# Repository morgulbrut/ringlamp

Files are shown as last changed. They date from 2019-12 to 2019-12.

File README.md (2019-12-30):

# ringlamp

Neopixel ringlamp, programmed in CircuitPython

## Repo

### housing

OpenSCAD file to generate the housing

### hardware

Hardware related stuff

### software

CircuitPython software.

#### code.py

Main: reads in 3 pots, and one switch.

The switch switches trough 6 modes, where the pots have slightly different functions:

 * **Mode 1:** warmwhite 
    * pot 1 sets the brightness
 * **Mode 2:** coldwhite 
    * pot 1 sets the brightness
 * **Mode 3:** RGB
    * pot 1 sets red
    * pot 2 sets green
    * pot 3 sets blue
 * **Mode 4:** split colors, half of the circle gets one color, the other half a second
    * pot 1 sets the brightness
    * pot 2 sets the rotation angle
    * pot 3 sets 10 different presets
 *  **Mode 5:** colorwheel
    * pot 1 sets the brightness
    * pot 2 rotates through the colorwheel
 * **Mode 6:** blend colors, every other LED gets color 1 or color 2 
    * pot 1 sets the brightness
    * pot 2 rotates through the colorwheel for color 1
    * pot 2 rotates through the colorwheel for color 2

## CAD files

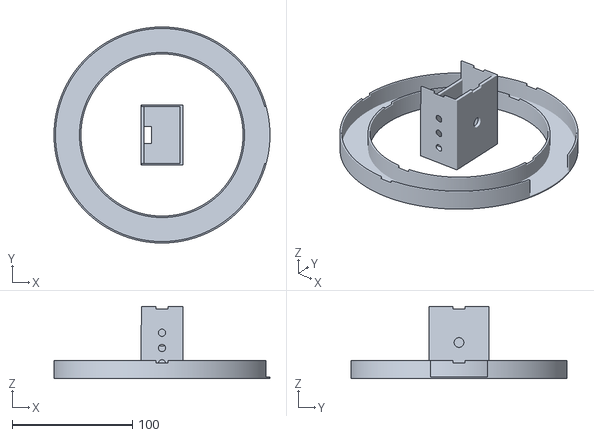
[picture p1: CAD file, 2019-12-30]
housing/ringlamp.stl
179.4 x 179.4 x 60.0

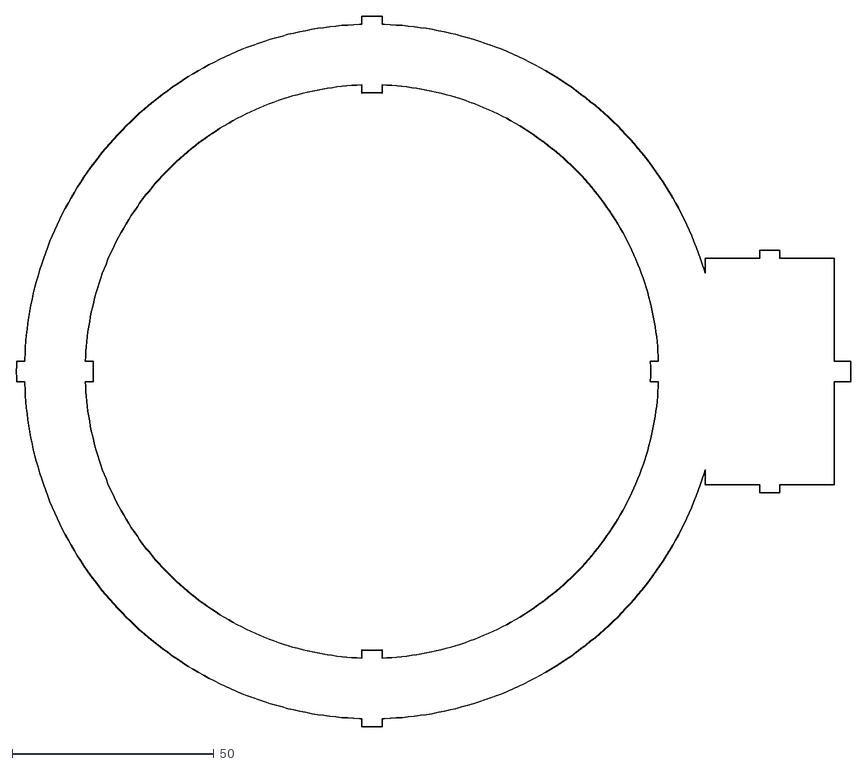
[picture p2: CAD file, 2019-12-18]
housing/cover.dxf
206.5 x 176.0

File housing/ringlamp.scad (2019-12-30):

LedRingDiameter = 157;   // [20:200]
LedRingWidth = 20;       // [5:20]
LedRingHeight = 15;      // [10:20]
WallThickness = 1.2;       // [1.0, 1.2, 2.0, 2.4, 4.0]
CompartementWidth = 50;  // [20:80]
CompartementHeight = 35; // [20:80]
CompartementLength = 60; // [20:120]
PotDistance = 12.7;        // [10.0, 12.7, 60.0]
PotCount = 3;            // [2:4]
PotShaft = 6;            // [4:10]
PlexiThickness = 2.0;    // [1.5, 2.0, 2.5, 3, 3.5, 4.0]
PlexiWidth = 10;         // [3:10]
ShowPart = 2;            // [0:Cover, 1:Cover2D, 2:Body, 3:BodyMounted, 4:All, 5:AllMounted]

inner1 = LedRingDiameter/2-WallThickness-LedRingWidth/2;
outer1 = LedRingDiameter/2+WallThickness+LedRingWidth/2;
inner2 = LedRingDiameter/2-LedRingWidth/2;
outer2 = LedRingDiameter/2+LedRingWidth/2;

compDist = sqrt(outer1*outer1-(CompartementWidth/2)*(CompartementWidth/2));

/* makes a ring
 o is the outer diameter
 i is the inner diameter
 h is the height
*/
module ring(o,i,h){
    difference(){
        cylinder($fn=360,h = h, r = o, center = false);
        translate([0,0,-.5]){
            cylinder($fn=360,h = h+1, r = i, center = false);
        }
    }
}


/* makes a cross out f two cubes, o x PlexiWidth x PlexiThickness
  for a plexi connections
  l is the size 
*/
module plexiCons(l){
    translate([0,0,(PlexiThickness+1)/2]){
        union(){
            cube([l+PlexiWidth,PlexiWidth,PlexiThickness+1],true);
            cube([PlexiWidth,l+PlexiWidth,PlexiThickness+1],true);
        }
    }
}


/* makes a bunch of holes for pots */
module potentiometers(){
    rotate([90,0,0]){
        for (a = [0 : PotCount - 1]) {
            translate([0,a*PotDistance,0]){
                cylinder($fn=360,h = CompartementWidth, r = PotShaft/2 , center = false);
            }
        }
    } 
}


/* makes the cover to lasercut */
module cover(){
    color("white"){
        difference(){
            union(){
                ring(outer1-0.1,inner1+0.1,PlexiThickness-0.1);
                translate([compDist+CompartementHeight/2-WallThickness,0,PlexiThickness/2]){
                    cube([CompartementHeight+WallThickness,CompartementWidth-0.1,PlexiThickness-0.1],true);
                }
            }
            translate([0,0,PlexiThickness]){
                body();
            }
        }
    }
}


/* makes the compartement for the controller to 3d print */
module controllerCompartement(){
    color("red"){
        translate([0,0,CompartementLength/2]){
            difference(){
                // outer cube
                cube([CompartementHeight,CompartementWidth,CompartementLength],true);
                translate([0,0,WallThickness]){
                    // make a shelF
                    cube([CompartementHeight-4*WallThickness,CompartementWidth-2*WallThickness,CompartementLength],true);   
                }
                translate([-(CompartementHeight/2),0,CompartementLength/2-LedRingHeight/2]){
        
                        cube([WallThickness,CompartementWidth+1,LedRingHeight+1],true); 
                        cube([CompartementHeight,CompartementWidth-2*WallThickness,LedRingHeight+1],true);
                }
                // holes for pots
                translate([0,0,-CompartementLength/2+PotDistance]){
                    potentiometers();
                }
                // notches for the plexi 
                translate([0,0,CompartementLength/2-PlexiThickness]){
                    plexiCons(90);
                }
                // mounting hole
                rotate([0,90,0]){
                    cylinder($fn=360,h = CompartementWidth, r = 4 , center = false);
                }
                // switch mounting hole
                rotate([-90,0,0]){
                    cylinder($fn=360,h = CompartementWidth, r = 3.1 , center = false);
                }
                // USB port
                translate([-CompartementHeight/2+4*WallThickness,0,-CompartementLength/2]){
                    cube([8,14,10],true);
                }
            }  
        }
    }
}


/* makes the ring for the LEDs to 3d print*/
module ledRing(){
    color("blue"){
        cutout = CompartementWidth-2*WallThickness;
        difference(){
            ring(outer1,inner1,LedRingHeight); 
            translate([0,0,WallThickness]){
                ring(outer2,inner2,LedRingHeight); 
            }
            translate([outer2-10,-cutout/2,WallThickness]){
                cube([20,cutout,LedRingHeight],false);   
            }
            translate([0,0,LedRingHeight-PlexiThickness]){
                plexiCons(outer1*2);
            }
        }
    }
}

/* connects a ring and a controller compartement to visualise the printed parts mounted */
module body(){
    translate([compDist+CompartementHeight/2,0,-(CompartementLength)]){
        controllerCompartement() ;
    }
    translate([0,0,-LedRingHeight]){
        ledRing();
    }
}



module ledRingCPL(){
    body();
    translate([0,0,-PlexiThickness]){
        cover();
    } 
}

if (ShowPart==0) cover();

if (ShowPart==1){
    render(){
        projection(){
            cover();
        }
    }
}

if (ShowPart==2){
    if (inner1 > CompartementWidth && inner1 > CompartementHeight ){
        controllerCompartement();
        ledRing();
    } else {
        controllerCompartement();
        translate([outer1+CompartementHeight,0,0]){
            ledRing();
        }
    }
}

if (ShowPart==3) body();

if (ShowPart==4){
    controllerCompartement();
    ledRing();
    translate([-LedRingDiameter-100,0,0]){
        cover();
    }
}

if (ShowPart==5) ledRingCPL();

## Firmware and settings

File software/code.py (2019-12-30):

from ring import Ring, Colors
import time
import digitalio
import board
import analogio


def ready():
    r.set_brightness(0.1)
    r.fill(Colors.GREEN)
    time.sleep(.5)
    r.fill(Colors.hex2rgb('#ffaa00'))
    time.sleep(.5)
    r.split_colors(Colors.BLUE,Colors.RED)
    time.sleep(1)
    r.blend_colors(Colors.COLDWHITE,Colors.YELLOW)
    time.sleep(1)
    r.fill(Colors.BLACK)


def get_value(pin):
    return (pin.value) / 65536.0



def get_byte_value(pin):
    return int((pin.value * 255) / 65536)


def main():
    mode = 3 # see README.md
    
    mode_sw = digitalio.DigitalInOut(board.D4)
    mode_sw.direction = digitalio.Direction.INPUT
    mode_sw.pull = digitalio.Pull.UP

    pot1 = analogio.AnalogIn(board.D1)
    pot2 = analogio.AnalogIn(board.D2)
    pot3 = analogio.AnalogIn(board.D3)

    while True:
        if not mode_sw.value:
            mode = (mode + 1) % 6
            time.sleep(0.2)
        if mode == 0:
            r.fill(Colors.WARMWHITE)
            r.set_brightness(get_value(pot1)*.7)
        elif mode == 1:
            r.fill(Colors.COLDWHITE)
            r.set_brightness(get_value(pot1)*.7)
        elif mode == 2:
            rval = get_byte_value(pot1)
            gval = get_byte_value(pot2)
            bval = get_byte_value(pot3)
            r.fill((rval,gval,bval))
            r.set_brightness(.7)
        elif mode == 3:
            start = int(get_value(pot2)* 60)
            cols = int(get_value(pot3)* 11)
            if cols == 0:
                r.split_colors(Colors.WARMWHITE,Colors.BLACK, start)
            elif cols == 1:
                r.split_colors(Colors.COLDWHITE,Colors.BLACK, start)
            elif cols == 2:
                r.split_colors(Colors.GREEN,Colors.WARMWHITE, start)
            elif cols == 3:
                r.split_colors(Colors.RED,Colors.WARMWHITE, start)
            elif cols == 4:
                r.split_colors(Colors.BLUE,Colors.WARMWHITE, start)
            elif cols == 5:
                r.split_colors(Colors.RED,Colors.GREEN, start)
            elif cols == 6:
                r.split_colors(Colors.RED,Colors.BLUE, start)
            elif cols == 7:
                r.split_colors(Colors.RED,Colors.YELLOW, start)
            elif cols == 8:
                r.split_colors(Colors.BLUE,Colors.YELLOW, start)
            elif cols == 9:
                r.split_colors(Colors.ORANGE,Colors.GREEN, start)
            else:
                r.split_colors(Colors.BLUE,Colors.BLACK, start)
            r.set_brightness(get_value(pot1)*.7)
        elif mode == 4:
            r.fill(Colors.wheel(get_byte_value(pot2)))
            r.set_brightness(get_value(pot1)*.7)
        elif mode == 5:
            col1 = Colors.wheel(get_byte_value(pot2))
            col2 = Colors.wheel(get_byte_value(pot3))
            r.blend_colors(col1,col2)
            r.set_brightness(get_value(pot1)*.7)
        else:
            r.fill(Colors.BLACK)

if __name__ == '__main__':
    r = Ring(60)
    #ready()
    main()

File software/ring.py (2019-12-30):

import board
import neopixel

class Colors:
    BLACK = (0,0,0)
    RED = (255, 0, 0)
    YELLOW = (255, 150, 0)
    GREEN = (0, 255, 0)
    CYAN = (0, 255, 255)
    BLUE = (0, 0, 255)
    PURPLE = (180, 0, 255)
    COLDWHITE = (255,255,200)
    WARMWHITE = (255,200,70)
    CANDLELIGHT = (255,150,40)
    ORANGE = (255,40,0)

    def hex2rgb(value):
        value = value.lstrip('#')
        lv = len(value)
        return tuple(int(value[i:i + lv // 3], 16) for i in range(0, lv, lv // 3))
    
    def wheel(pos):
    # Input a value 0 to 255 to get a color value.
    # The colours are a transition r - g - b - back to r.
        if pos < 1:
            return (Colors.WARMWHITE)
        if pos < 85:
            return (255 - pos * 3, pos * 3, 0)
        if pos < 170:
            pos -= 85
            return (0, 255 - pos * 3, pos * 3)
        pos -= 170
        return (pos * 3, 0, 255 - pos * 3)

class Ring:
    global pixels
    global num_pixels

    def __init__(self,num_pixels):
        Ring.num_pixels = num_pixels
        Ring.pixels = neopixel.NeoPixel(board.D0, num_pixels, brightness=0.3, auto_write=False)

    def fill(self,color):
        Ring.pixels.fill(color)
        Ring.pixels.show()
    
    def blend_colors(self,color1,color2):
        for i in range(Ring.num_pixels):
            if i % 2 == 0:
                Ring.pixels[i] = color1
            else:
                Ring.pixels[i] = color2
        Ring.pixels.show()


    def split_colors(self,color1,color2, start = 0):
        for i in range(Ring.num_pixels):
            n = (i + start) % Ring.num_pixels
            if i < Ring.num_pixels/2:
                Ring.pixels[n] = color1
            else:
                Ring.pixels[n] = color2
        Ring.pixels.show()

    def set_brightness(self,brightness):
        Ring.pixels.brightness = brightness
        Ring.pixels.show()

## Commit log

2019-12-18 output generated
    [cover.dxf, ringlamp.scad, ringlamp.stl]
2019-12-18 Implented views fixed initial vals
    [ringlamp.scad]
2019-12-20 first build
    [ringlamp.scad, ringlamp.stl]
2019-12-30 fixed some values to make printing faster (on my printer)
    [ringlamp.scad, ringlamp.stl]
